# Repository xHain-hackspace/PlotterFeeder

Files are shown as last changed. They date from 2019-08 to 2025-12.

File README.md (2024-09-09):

# PlotterFeeder

## Overview 

ESP32 Firmware to feed HPGL (a control language for plotters) to a pen plotter. For info about HPGL, see wikipedia and the original [Programming Manual](https://raw.githubusercontent.com/xHain-hackspace/PlotterFeeder/master/7550A_ProgrammingManual_OCR.pdf) included in this repo.

This project uses an ESP32 board in connection with a suitable RS232 level shifter to control HP Plotters, in our case a HP 7550A. See [https://www.sparkfun.com/tutorials/215](https://www.sparkfun.com/tutorials/215) for details on why you need a level shifter.

The hardware basically consists of 5 LEDs, 5 Buttons, and a RS232-to-TTL level shifter which interfaces to the plotters data-in, data-out, and buffer-full signal lines (plus ground connection). There is a very rudimentary hardware documentation available in [this folder](hardware).

There are multiple things that the code can do: standalone plot from flash, plot via WiFi, remote control via Wifi, and play games.

### Plot from Flash

When pressing one of the 5 input buttons, data is sent from flash to the plotter. The data is defined in [src/vectors.h](src/vectors.h) and HPGL data for vector graphics can easily be generated from Inkscape (Extensions->Export->Plot. For settings, see [svgs/plotter-settings.png](svgs/plotter-settings.png), then copy the HPGL data string from the debug output and insert into [src/vectors.h](src/vectors.h). You may need to break a large string into multiple smaller strings if you experience crashes or unstable behavior.

### Plot via WiFi

Clients can send HPGL data to the plotter via Wifi. The plotter can operate in two modes: Access Point and Station mode. You can switch between these modes by setting `WIFI_MODE` in [src/main.cpp](src/main.cpp#L33).

Access point mode is currently being used as the default. In access point mode, the plotter opens its own WiFi access point. The corresponding settings are defined in [src/main.cpp](src/main.cpp#L34-L38). With standard settings, you should be able to connect to "xHain Plotter" with password "plotterpassword". You will need to give yourself a static IP of e.g. `192.168.4.42`, as there is no DHCP implemented. Once connected, use [src/send_HPGL_wifi.py](src/send_HPGL_wifi.py) to send data to the plotter. The data will simply be handed over to the plotter as-is. Thus, you can send any valid HPGL commands. For testing, try absolute positioning commands and see if the plotter moves. E.g. use a text file with `PA 0,0;PA 1000,1000;` as input or generate data from some simple graphic in Inkscape. This is also a good way to quickly test your own HPGL code.

In station mode, the plotter will connect to an existing WiFi network. You can configure the corresponding SSID and password using the settings in [src/main.cpp](src/main.cpp#L34-L36). Once the plotter is connected, any other client inside the network can use [src/send_HPGL_wifi.py](src/send_HPGL_wifi.py) to send data as mentioned above.

### Remote control via Wifi

The setup for this is the same as for [Plot via WiFi](#plot-via-wifi). You can use [src/remotecontrol_wifi.py](src/remotecontrol_wifi.py) to control the plotter pen with a USB joystick over WiFi. Use the joystick to move the pen and hold the button to put the pen down. Have fun akwardly drawing things in a completely overengineered way. :)

### Play Games

Buttons can also trigger games if configured so in [src/main.cpp](src/main.cpp). Instead of calling `send_buffered()` to send data from flash to the plotter, a game can be run when the corresponding button is pressed. `dart_game()` is a game where the plotter will draw a target and then rapidly move the pen randomly and when the user presses the button again, an arrow is 'shot' (=drawn) at the current position. The user can then 'shoot' a few more arrows and finally the achieved total score will be plotted and the paper ejected.

## Testing Plotters via USB-Serial Adapters

To test your designs via Inkscape plotter plugins or similar scripts, you can use an USB-serial adapter instead of the plotter feeder hardware and make a cable with the following connections. (These are an example, you might have to adapt them to your specific plotter.) Be aware that some cheap adapters will not produce the correct RS232 negative and positive voltages for this to work. E.g. they might produce 0V and +5V instead of -5V and +5V. If unsure, simply measure the voltages on the data lines of your adapter. This cable can be used with RTS/CTS flow control. Make sure your plotter is set up correctly, and also be aware of different pinout on different plotters, check e.g. chapter 16 in the [programming manual](https://raw.githubusercontent.com/xHain-hackspace/PlotterFeeder/master/7550A_ProgrammingManual_OCR.pdf) or the pinouts in the manual of your specific plotter. A good place to find manuals is the 'product documentation' link on the plotter sites at http://www.hpmuseum.net/exhibit.php?class=4&cat=24 .

| D-sub 9 female connector (USB-serial Adapter side) pin number | D-sub 25 connector (plotter side, male for HP7470A, female for HP7550A) pin number |
|---|---|
| 1 | no connection |
| 2 (RXD, to PC) | 2 (TD, transmitted data, from plotter) |
| 3 (TXD, from PC) | 3 (RD, received data, to plotter) |
| 4 | no connection |
| 5 (Ground) | 7 (SGND, signal ground) |
| 6 (DSR, to PC) | 4 (RTS, request to send, from plotter) |
| 7 | no connection |
| 8 (CTS, to PC) | 20 (DTR, data terminal ready, from plotter) |
| 9 | no connection |

For HP7550A, you should use a *female* D-sub 25 connector on the *computer/modem* port. Set the plotter to the following settings:
Standalone/Eavesdrop -> use Standalone, Remote/Local/Standby -> use Remote, use RTS/CTS flow control on the PC.

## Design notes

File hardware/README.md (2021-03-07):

This folder contains a very rudimentary hardware documentation. Sorry, we did not yet have time to make a circuit diagram. If you make one, please make sure to send us a pull request or the data. Thanks. :)

The cable going to the plotter seen in the images is connected to the 'computer/modem' port on a HP7550A as follows:
|Cable Color | Plotter Pin|
|---|---|
|Orange | pin 20 (DTR, data terminal ready, from plotter)|
|Green | pin 3 (RD, received data, to plotter)|
|Red | pin 2 (TD, transmitted data, from plotter)|
|Black | pin 7 (signal ground)|

The LEDs/buttons are in standard configuration (Buttons: direct connection to ground when pressed, LEDs: series resistor)

The converter chip is a MAX232. Since it's 5 Volts, the are two resistive dividers on the bottom for level shifting 5V from the MAX232 to 3.3V for the ESP32 input. The level shifter each use 3 resistors instead of two, because we did not have the correct values when building. The connection from ESP 3.3V to MAX232 5V input is just a direct connection. (3.3V high level is OK for 5V inputs)

There are also two pullup resistors for the buttons, because some ESP32 pins do not have internal pullups.

The HP7550A is set to 'Standalone configuration' and 'remote mode', see the manual (https://raw.githubusercontent.com/xHain-hackspace/PlotterFeeder/master/7550A_ProgrammingManual_OCR.pdf) for details.

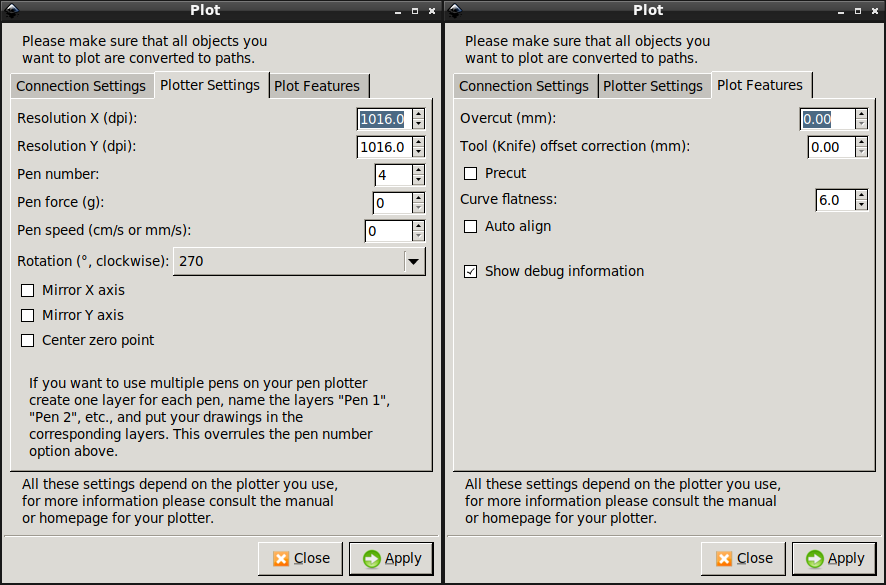
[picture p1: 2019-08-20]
svgs/plotter-settings.png

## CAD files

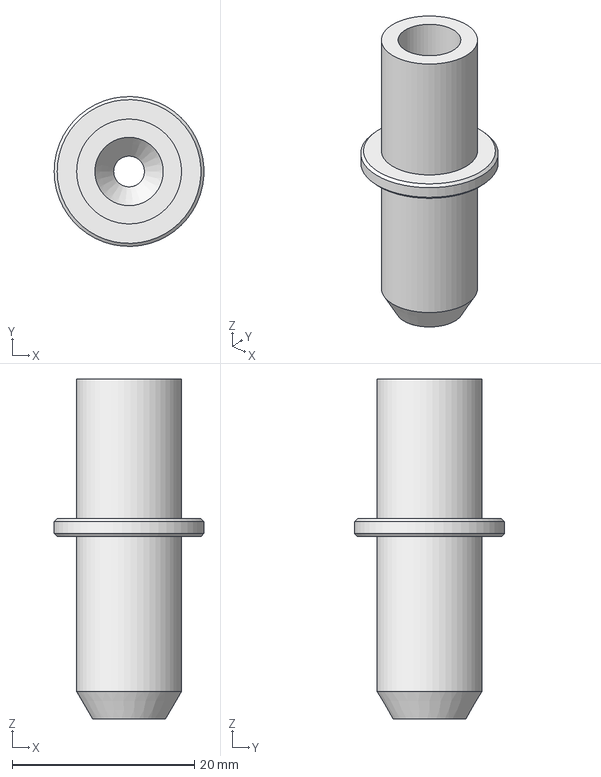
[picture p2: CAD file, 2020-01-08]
CAD/CAD-Plotter-Pen.FCStd
16.4 x 16.4 x 37.3 mm

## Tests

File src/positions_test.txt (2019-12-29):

IN;SP2;

PA5350,3750;CI400;CI800;CI1600;CI2400;

PA500,200;LBTry to hit the target: Press button again to launch your arrow! Ready? ;
LB3 ;
LB2 ;
LB1 ;
LBGo! ;

LB<-------<<;

PA 0,0;

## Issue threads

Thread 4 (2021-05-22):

Roland DXY-1300

koraysels, 2021-05-22:
Hi man, \
i have a roland DXY-1350 (same as DXY-1300) which i am currently controlling with a serial<>Usb cable on my mac with the awesome (chiplotle)[http://sites.music.columbia.edu/cmc/chiplotle/]

I was wondering if the ESP-32 could directly interface with the serial port ? or why did you need the level shifters?

arglurgl, 2022-03-24:
Hey @koraysels
the converter is needed because RS-232 uses voltages that the ESP can not produce. You need negativ and positive voltages eg +12V and -12V, or +3V and -3V, see https://en.wikipedia.org/wiki/RS-232#Voltage_levels . The ESP can only do 0V and 3.3V Volt which works on some RS-232 devices, but is not in standard specification and especially for this plotter it does not work. I hope this answers your question. Feel free to reopen if needed.

Closed 2022-03-24.

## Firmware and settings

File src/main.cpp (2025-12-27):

#include <Arduino.h>
#include <HardwareSerial.h>
#include <WiFi.h>
#include "vectors.h"

//Plotter Interface
#define CLEAR_TO_SEND_IN_PIN 21
#define TX_OUT_PIN 22
#define RX_IN_PIN 23

//LEDs
#define LED1_PIN 13
#define LED2_PIN 12
#define LED3_PIN 14
#define LED4_PIN 27
#define LED5_PIN 26
#define NR_OF_LEDS 5

//Buttons
#define BUT1_PIN 25
#define BUT2_PIN 33
#define BUT3_PIN 32
#define BUT4_PIN 35
#define BUT5_PIN 34

//Delay
#define SWIPE_DELAY 50

//Dart Game
#define DART_COUNTDOWN_DELAY 1000

//WiFi
// WiFi mode is now selected via buttons in setup
#define WIFI_SSID               "xHain"
#include "wifi_password.h" //make sure to create wifi_password.h, see wifi_password.h.example file
#define WIFI_INPUT_BUFFER_SIZE  255
#define WIFI_CHANNEL            5
#define WIFI_MAX_CONNECTIONS    1
#define HOSTNAME                "harryplotter"
#define LISTEN_PORT             1337

IPAddress local_IP(192,168,4,1);
IPAddress gateway(192,168,4,13);
IPAddress subnet(255,255,255,0);

WiFiServer wifiServer(LISTEN_PORT);
WiFiClient client;
char wifi_input_buffer[WIFI_INPUT_BUFFER_SIZE];
wifi_mode_t selected_wifi_mode = WIFI_OFF;

HardwareSerial PlotterSerial(1);

void wifi_ap() {
  Serial.println("Starting Wifi...");
  Serial.print("Setting soft-AP configuration ... ");
  Serial.println(WiFi.softAPConfig(local_IP, gateway, subnet) ? "Ready" : "Failed!");

  Serial.print("Setting soft-AP ... ");
  Serial.println(WiFi.softAP(WIFI_SSID, WIFI_PASSWORD, WIFI_CHANNEL, false, WIFI_MAX_CONNECTIONS) ? "Ready" : "Failed!");

  Serial.print("Soft-AP IP address = ");
  Serial.println(WiFi.softAPIP());
}

void wifi_connect() {
  Serial.print("Connecting to ");
  Serial.print(WIFI_SSID);

  WiFi.setHostname(HOSTNAME);
  WiFi.begin(WIFI_SSID, WIFI_PASSWORD);
  while (WiFi.status() != WL_CONNECTED) {
      delay(500);
      Serial.print(".");
  }

  Serial.println("");
  Serial.println("WiFi connected");
  Serial.print("Hostname: ");
  Serial.println(HOSTNAME);
  Serial.print("IP Address: ");
  Serial.println(WiFi.localIP());
}

uint8_t button_pressed(){
  if(!digitalRead(BUT1_PIN))      return 1;
  else if(!digitalRead(BUT2_PIN)) return 2;
  else if(!digitalRead(BUT3_PIN)) return 3;
  else if(!digitalRead(BUT4_PIN)) return 4;
  else if(!digitalRead(BUT5_PIN)) return 5;
  else return 0;
}

void leds_off(){
  digitalWrite(LED1_PIN,LOW);
  digitalWrite(LED2_PIN,LOW);
  digitalWrite(LED3_PIN,LOW);
  digitalWrite(LED4_PIN,LOW);
  digitalWrite(LED5_PIN,LOW);
}

void leds_on(){
  digitalWrite(LED1_PIN,HIGH);
  digitalWrite(LED2_PIN,HIGH);
  digitalWrite(LED3_PIN,HIGH);
  digitalWrite(LED4_PIN,HIGH);
  digitalWrite(LED5_PIN,HIGH);
}

void leds_flash_on_off(){
  leds_on();
  delay(500);
  leds_off();
  delay(500);
}

void leds_swipe_until_user_input(){
  int leds[] = {LED1_PIN,LED2_PIN,LED3_PIN,LED4_PIN,LED5_PIN};
  int current_led=0;
  int current_swipe = 0;

  //do the effect
  while(!button_pressed() && !(client=wifiServer.available())){//return if pressed, or client connects, save client object
    
    //set the current led according to swipe
    if (current_swipe == 0) digitalWrite(leds[current_led],HIGH);
    else if (current_swipe == 1) digitalWrite(leds[current_led],LOW);
    current_led++;

    //update status variables
    if (current_led == NR_OF_LEDS){
      current_led = 0;
      current_swipe++;
      if (current_swipe==2) current_swipe = 0;
    } 

    delay(SWIPE_DELAY);
  }

  //Switch everything off before returning
  digitalWrite(LED1_PIN,LOW);
  digitalWrite(LED2_PIN,LOW);
  digitalWrite(LED3_PIN,LOW);
  digitalWrite(LED4_PIN,LOW);
  digitalWrite(LED5_PIN,LOW);
}

void test_buttons_and_led(){
    if(!digitalRead(BUT1_PIN)) digitalWrite(LED1_PIN,HIGH);
    else digitalWrite(LED1_PIN,LOW);
    
    if(!digitalRead(BUT2_PIN)) digitalWrite(LED2_PIN,HIGH);
    else digitalWrite(LED2_PIN,LOW);

    if(!digitalRead(BUT3_PIN)) digitalWrite(LED3_PIN,HIGH);
    else digitalWrite(LED3_PIN,LOW);

    if(!digitalRead(BUT4_PIN)) digitalWrite(LED4_PIN,HIGH);
    else digitalWrite(LED4_PIN,LOW);

    if(!digitalRead(BUT5_PIN)) digitalWrite(LED5_PIN,HIGH);
    else digitalWrite(LED5_PIN,LOW);
}

void send_buffered(const char input_chars[]){
  String input = input_chars;
  const uint max_blocksize = 70;
  uint inlen = input.length();

  // buffer for storing the string fragment
  String fragment;
  // number of chars that will be read into buffer
  //uint readlen;
  ulong full_blocks = inlen/max_blocksize;

  //handle full blocks
  for (int current_block=0; current_block < full_blocks; current_block++){
    fragment = input.substring(current_block*max_blocksize, current_block*max_blocksize+max_blocksize);
    PlotterSerial.flush();//wait for all bytes to be sent from previous block in esp's internal buffer
    while(digitalRead(CLEAR_TO_SEND_IN_PIN)) {delay(50);}//check if plotter is ready to receive new block
    PlotterSerial.write(fragment.c_str());//send block    
  }

  //handle last partial block
  if(full_blocks*max_blocksize < inlen){
    fragment = input.substring(full_blocks*max_blocksize, inlen);//copy last partial block
    PlotterSerial.flush();//wait for all bytes to be sent from previous block in esp's internal buffer
    while(digitalRead(CLEAR_TO_SEND_IN_PIN)) {delay(50);}//check if plotter is ready to receive new block
    PlotterSerial.write(fragment.c_str());//send block   
  }
}

void print_id(){
  Serial.println("Getting ID");
  PlotterSerial.write("OI;");
  delay(100);  
  Serial.println("Response:");
  Serial.println(PlotterSerial.readStringUntil('\r'));
}

void autofeed_paper(){
  PlotterSerial.write("PG;");
}

void dart_game(){
  uint target_middle_x =5350;
  uint target_middle_y = 3750;
  char stringBuffer[100];
  //init/select pen
  send_buffered("IN;SP2;");
  //go to target position
  sprintf(stringBuffer,"PA%d,%d;",target_middle_x,target_middle_y);
  send_buffered(stringBuffer);
  //draw target
  send_buffered("CI400;CI800;CI1600;CI2400;");
  //draw info text
  send_buffered("PA500,200;LBTry to hit the target: Press button now to launch arrow. Press+hold again to hit the target.;");
  delay(20000);//adjust this at least to the time it takes to plot the previous stuff
  //go to "text view" position
  //go to score position
  sprintf(stringBuffer,"PA%d,%d;",100,7000);
  send_buffered(stringBuffer);
  //wait for button press and release
  while(!button_pressed()){delay(50);}
  while(button_pressed()){delay(50);}
  // //draw countdown
  // send_buffered("LB3   ;");
  // delay(DART_COUNTDOWN_DELAY);
  // send_buffered("LB2   ;");
  // delay(DART_COUNTDOWN_DELAY);
  // send_buffered("LB1   ;");
  // delay(DART_COUNTDOWN_DELAY);
  // send_buffered("LBGo! ;");
  // delay(DART_COUNTDOWN_DELAY);
  //move pen and wait for any button
  uint score = 0;

  uint current_position_x=0;
  uint current_position_y=0;

  for (int i=0; i<5; i++){
    while(!button_pressed()){
      current_position_x = target_middle_x + random(-2400,2400);
      current_position_y = target_middle_y + random(-2400,2400);
      sprintf(stringBuffer,"PA%d,%d;",current_position_x,current_position_y);
      send_buffered(stringBuffer);
      delay(250);
    }
  
    //plot arrow
    send_buffered("LB<-------<<;");
    delay(1000);
    //determine score
    score += 3000- sqrt(pow(target_middle_x - current_position_x*1.0,2)+ pow(target_middle_y - current_position_y*1.0,2)*1.0);

    // wait until button is released
    while(button_pressed()){delay(50);}
  }

  //go to score position
  sprintf(stringBuffer,"PA%d,%d;",1000,1000);
  send_buffered(stringBuffer);
  //plot score text
  sprintf(stringBuffer,"LBYour score is: %d Thanks for playing. :)\n\nx-hain.de, Gruenberger Str. 16, 10243 Berlin;",score);
  send_buffered(stringBuffer);
  //eject paper
  autofeed_paper();  
  while(button_pressed());//wait for button to be released, so we dont immediately go to game again
}

void setup() {
  //Configure Pins
  pinMode(LED_BUILTIN, OUTPUT);
  pinMode(CLEAR_TO_SEND_IN_PIN, INPUT);

  pinMode(LED1_PIN, OUTPUT);
  pinMode(LED2_PIN, OUTPUT);
  pinMode(LED3_PIN, OUTPUT);
  pinMode(LED4_PIN, OUTPUT);
  pinMode(LED5_PIN, OUTPUT);

  pinMode(BUT1_PIN, INPUT_PULLUP);
  pinMode(BUT2_PIN, INPUT_PULLUP);
  pinMode(BUT3_PIN, INPUT_PULLUP);
  pinMode(BUT4_PIN, INPUT_PULLUP);
  pinMode(BUT5_PIN, INPUT_PULLUP);

  Serial.begin(9600);
  while (!Serial) {
    ; // wait for Serial port to connect.
  }
  Serial.println("Starting up...");

  PlotterSerial.begin(9600, SERIAL_8N1, RX_IN_PIN, TX_OUT_PIN);//Baud,Mode, RX Pin (In), TX Pin (Out)

  Serial.println("Waiting for WiFi Selection...");
  // enable LEDs to signal choices
  digitalWrite(LED1_PIN,HIGH);
  digitalWrite(LED2_PIN,HIGH);
  digitalWrite(LED3_PIN,HIGH);
  //wait for button press
  uint8_t button = 0;
  unsigned long wifi_sel_start = millis();
  while (!(button=button_pressed()) && ((millis()-wifi_sel_start) < 5000) )
  {
    delay(100);
  }
  leds_off();
  delay(100);

  //evaluate button press or timeout
  switch(button)
  {
    case 1: selected_wifi_mode = WIFI_STA; break; // join network
    case 2: selected_wifi_mode = WIFI_AP; break; // open own AP
    case 3: selected_wifi_mode = WIFI_OFF; break; // WiFi off
    default: selected_wifi_mode = WIFI_STA; break; // timeout default: join network
  }

  // check what wifi setup is needed and do it
  if (selected_wifi_mode == WIFI_AP) {
    wifi_ap();
  } else if (selected_wifi_mode == WIFI_STA){
    wifi_connect();
  }

  if (!(selected_wifi_mode == WIFI_OFF)){
    Serial.print("Starting TCP server on port ");
    Serial.println(LISTEN_PORT);
    wifiServer.begin();
  }
}

void loop() {
  int received_data_count = 0;
  
  for (int i = 0; i < 3; i++) leds_flash_on_off();

  while(1){

    //lure people close with flashing lights
    leds_swipe_until_user_input();

    //Check for client connection
    if (client) {
      Serial.println("Client connected");
      leds_on();//indicate active connection      
      while (client.connected()) {//while someone is connected
        delay(10); //wait for some data to arrive
        received_data_count = 0;        
        while (client.available()>0 && received_data_count<(WIFI_INPUT_BUFFER_SIZE-1)) {//while data is available and input buffer not full
          //put available char into input buffer
          wifi_input_buffer[received_data_count] = client.read();  
          received_data_count++;        
        }
        if (received_data_count > 0){//if something was received
          //add extra null terminator for safety
          wifi_input_buffer[received_data_count] = 0;
          //send data to plotter
          Serial.println("Received data over WiFi:");
          Serial.println(wifi_input_buffer);
          //Send data to plotter
          send_buffered(wifi_input_buffer);
          //send acknowledgement to that data was sent to plotter
          if (client.connected()) client.write("OK");
        }      
      } //end while connection
      client.stop();
      client = 0; //reset global client variable
      Serial.println("Client disconnected");
      leds_off();//indicate disconnect
    }//end if client

    //check what is pressed
    delay(50); //debounce wait for the button
    if(!digitalRead(BUT1_PIN)) {
      digitalWrite(LED1_PIN,HIGH);
      send_buffered(vader);
      send_buffered(logo_for_vader);
      autofeed_paper();
    }else if(!digitalRead(BUT2_PIN)) {
      digitalWrite(LED2_PIN,HIGH);
      //send_buffered(xHain_flyer_cccamp);
      //send_buffered(xHain_flyer_cccamp_party);
      send_buffered(flyer_36c3);
      autofeed_paper();
    }else if(!digitalRead(BUT3_PIN)){
      digitalWrite(LED3_PIN,HIGH);
      dart_game();
      //send_buffered(dodekaeder1); 
      //send_buffered(dodekaeder2); 
      //send_buffered(dodekaeder3); 
      //autofeed_paper();
    }
    else if(!digitalRead(BUT4_PIN)) {
      digitalWrite(LED4_PIN,HIGH);
      send_buffered(rick); 
      //send_buffered(dode_info_en1); 
      //send_buffered(dode_info_en2); 
      //send_buffered(dode_info_en3); 
      //send_buffered(dode_info_en_red); 
      autofeed_paper();
    }
    else if(!digitalRead(BUT5_PIN)) {
      digitalWrite(LED5_PIN,HIGH);
      //send_buffered(dode_info_de1); 
      //send_buffered(dode_info_de2); 
      //send_buffered(dode_info_de3); 
      //send_buffered(dode_info_de_red); 
      //autofeed_paper(); 
    }   
  }
}

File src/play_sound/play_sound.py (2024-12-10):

import os
import time
from numpy import arange
from pysine import sine #for preview, to not use just comment out and define sine() as 'pass'/empty function
import serial
import socket

from melodies_twisst import *
from melodies_midi import *

class NetworkPlotter:
    def __init__(self, host, port) -> None:
        self.socket = socket.socket() 
        self.host = host
        self.port = port
        self.WIFI_INPUT_BUFFER_SIZE_ESP32 = 255 #must be the same as in esp32 plotterfeeder code
        
    def open(self):
        self.socket.connect((self.host, self.port))#connect to plotter, TODO: this hangs on "no reply"
        
    def write(self, send_data):
        #send data in chunks
        #print("Sending data...")
        #print(send_data.decode(), end="")
        for chunk in self._chunk_it(send_data, (self.WIFI_INPUT_BUFFER_SIZE_ESP32-1)):#dont forget added null terminator
            #print(chunk.decode("utf-8")) #print data that was sent
            self.socket.send(chunk)
            reply = self.socket.recv(2) #TODO: this hangs on "no reply"
            #print(reply.decode("utf-8"))
            if (reply != b'OK'):#we expect an "OK"  when the data has been sent to plotter
                self.socket.close()
                print("Error: Did not receive 'OK' after data chunk. Aborting.")
                break
    
    def close(self):
        self.socket.close()
        
    #helper function to split string in chunks
    def _chunk_it(self, lst, n):
        for i in range(0, len(lst), n):
            yield lst[i:i+n]
        

def preview_notes_speaker(notes_list):
    for note in notes_list:
        frequency = note[0]
        duration = note[1]

        if frequency == -1:
            time.sleep(duration)
        else:
            sine(frequency, duration)

def preview_notes_plotter(notes_list, plotter, transpose_factor, transpose_offset, start_at= None, stop_after=None):
    
    offset_other_axis = 0
    travel_limit = 4500
    travel_middle = travel_limit -500
    controlled_coordinate = travel_middle

    MM_PER_PLOTTER_UNIT = 0.025 # mm/pu     # HP 7470A
    
    plotter.write("IN;".encode()) # init
    plotter.write("PA0,0;PA100,100;".encode()) # go to home, prevents paper jams in some cases
    plotter.write(f"SP6;".encode()) # we hope pen 6 has the dummy pen
    plotter.write("PD;".encode()) # pen down (else speed wont work)
    plotter.write(f"PA{offset_other_axis:.4f},{controlled_coordinate:.4f};".encode())
    #plotter.write(f"PA{controlled_coordinate:.4f},{offset_other_axis:.4f};".encode())
    time.sleep(1)
    
    

    for index, note in enumerate(notes_list):
        frequency = note[0]
        duration = note[1]
        duration = duration
        print(index)
        
        if start_at is not None and index < start_at:
            continue

        if stop_after is not None and index > stop_after:
            break

        if frequency == -1:
            speed = 10
        else:            
            speed = transpose_factor*frequency + transpose_offset # cm/s, max 38.1, min 0.38 38 = 7700 Hz 5 1200,303. 10 1222
            #print(speed)
            if speed > 80:
                print(f"Warning: speed max truncated to 80, was {speed}")
                speed = 80
                
            elif speed < 1:
                print(f"Warning: speed min truncated to 1, was {speed}")
                speed = 1
         
        # calculate travel in plotter units
        travel_mm = (speed * 10) * duration
        travel_pu = travel_mm / MM_PER_PLOTTER_UNIT 

        extra_travel_times = 0
        if travel_pu > travel_limit: # check paper size
            extra_travel_times = int(travel_pu/travel_limit)
            travel_pu = travel_pu%travel_limit # TODO split in multiple moves instead of truncate
            #print("multitravel")
        
        plotter.write(f"VS{speed:.4f};".encode())
        
        for travel_nr in range(extra_travel_times,-1,-1):
            #print(travel_nr)
            if travel_nr > 1:
                this_step_travel = travel_limit
            else:
                this_step_travel = travel_pu
                
            if controlled_coordinate > travel_middle:
                controlled_coordinate -= this_step_travel
            else:
                controlled_coordinate += this_step_travel
        
            passive_coordinate = offset_other_axis         
            plotter.write(f"PA{passive_coordinate:.4f},{controlled_coordinate:.4f};".encode())
            #plotter.write(f"PA{controlled_coordinate:.4f},{passive_coordinate:.4f};".encode())
    

def main():
    #midipath = os.path.expanduser('~/Downloads/darude-sandstorm.mid')
    #song = get_song_midi(midipath,5)
    song = get_song_twisst(33)
    
    
    #preview_notes_speaker(song)
    
    portname = "/dev/ttyUSB0"
    baud = 9600
    #plotter = serial.Serial(portname, baud, bytesize=8, parity='N', stopbits=serial.STOPBITS_ONE,
    #                            timeout=5, xonxoff=False, rtscts=True)
    
    plotter = NetworkPlotter("harryplotter", 1337)
    
    transpose_factor = 5 * 8  / 440 #*0.25
    transpose_offset = 0
    start_at = None #100
    stop_after = 127 #140
    
    print(f"preview at offset {transpose_offset}, factor {transpose_factor}...")
    
    plotter.open() # not needed for serial, required for network
    preview_notes_plotter(song, plotter, transpose_factor, transpose_offset, start_at, stop_after)
    plotter.write(f"SP1;PU;PA500,500;LBYou have been rickrolled by Harry Plotter at xHain. Have a great day! :) \n\rVisit us at Garderobenfoyer 1 on 38C3 / x-hain.de / Gruenberger Str 16, 10243 Berlin\x03;".encode())
    plotter.close()

if __name__ == "__main__":
    main()

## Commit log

2018-12-29 bugs fixed, c-base flyer added
    [main.cpp]
2019-08-23 button4 preset fix
2019-08-29 Fix LED indicator bug, add helper files
    [main.cpp]
2019-12-28 Switch to pygame for joystick handling
2020-01-08 Create CAD-Plotter-Pen.FCStd
    CAD file for custom plotter pen
    [CAD-Plotter-Pen.FCStd]
2020-01-08 Add files via upload
    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
    [CAD-Plotter-Pen.FCStd]
2024-09-09 make comment show up in compile error
    [main.cpp]
2024-12-06 wrap loose code into main function and make it importable
    [play_sound.py]
2025-12-27 add wifi mode selection via buttons at boot
